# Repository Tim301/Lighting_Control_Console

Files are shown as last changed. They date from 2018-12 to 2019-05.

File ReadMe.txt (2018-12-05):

# Lighting_Control_Console
An open source lighting control console developed by MASTER's degree students of DREAM course at Valenciennes.
-> https://formations.uphf.fr/cdm/subProgram/FR_RNE_0593279U_PR_SOF-15676/FR_RNE_0593279U_PR_SOF-15679

DMX_Core.ino use Arduino Uno to create DMX512 signals for RS485 chip. // Actually in progress.
  Equipements:
   - Arduino Uno
   - Grove Dmx512 or similar
   - Cables
  How to use:
  Connect DMX chip input pin to Arduino's TX pin.
  
Attiny_Fader.ino use a Attiny85 to send and receive fader position by way of I2C.
  Equipements:
   - Attiny 85
   - L9110H H Bridge (DIP)
   - Motorized fader like SL9/01V96     // We use a PRO-Fader MF-914PFL-B10K-10V
 See Pinout:    // Not available yet

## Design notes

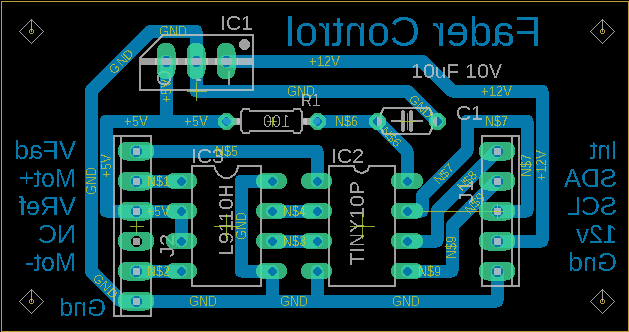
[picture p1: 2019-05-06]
PCB_Fader/PCB.png

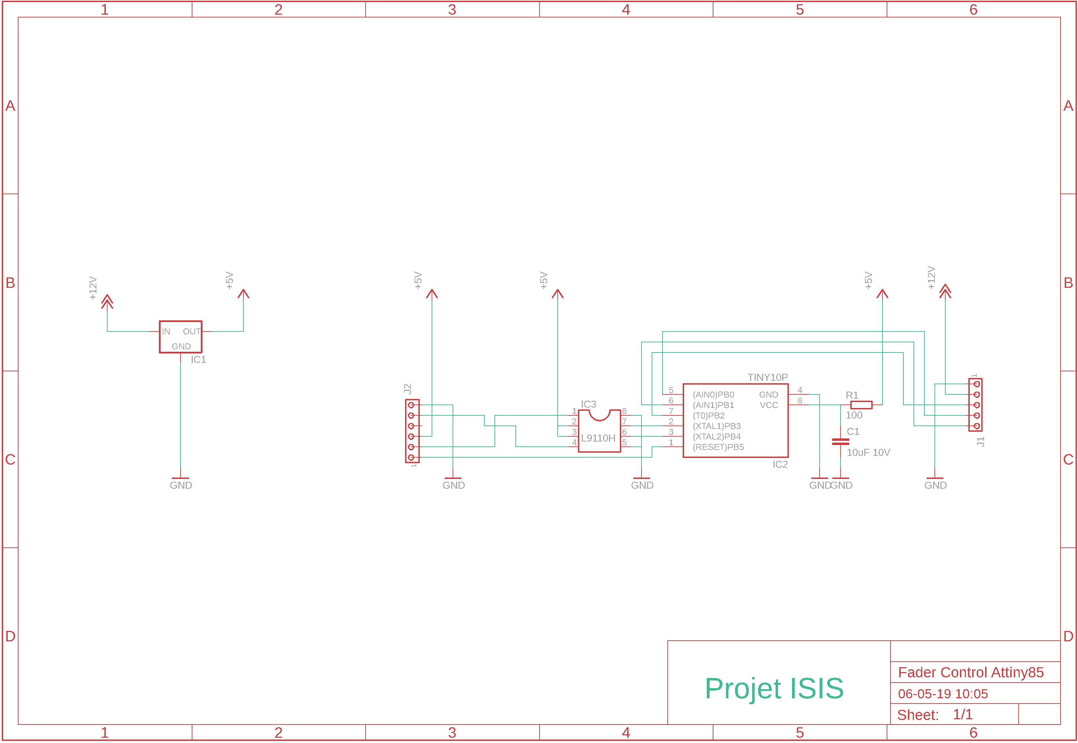
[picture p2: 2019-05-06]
PCB_Fader/Schema.png

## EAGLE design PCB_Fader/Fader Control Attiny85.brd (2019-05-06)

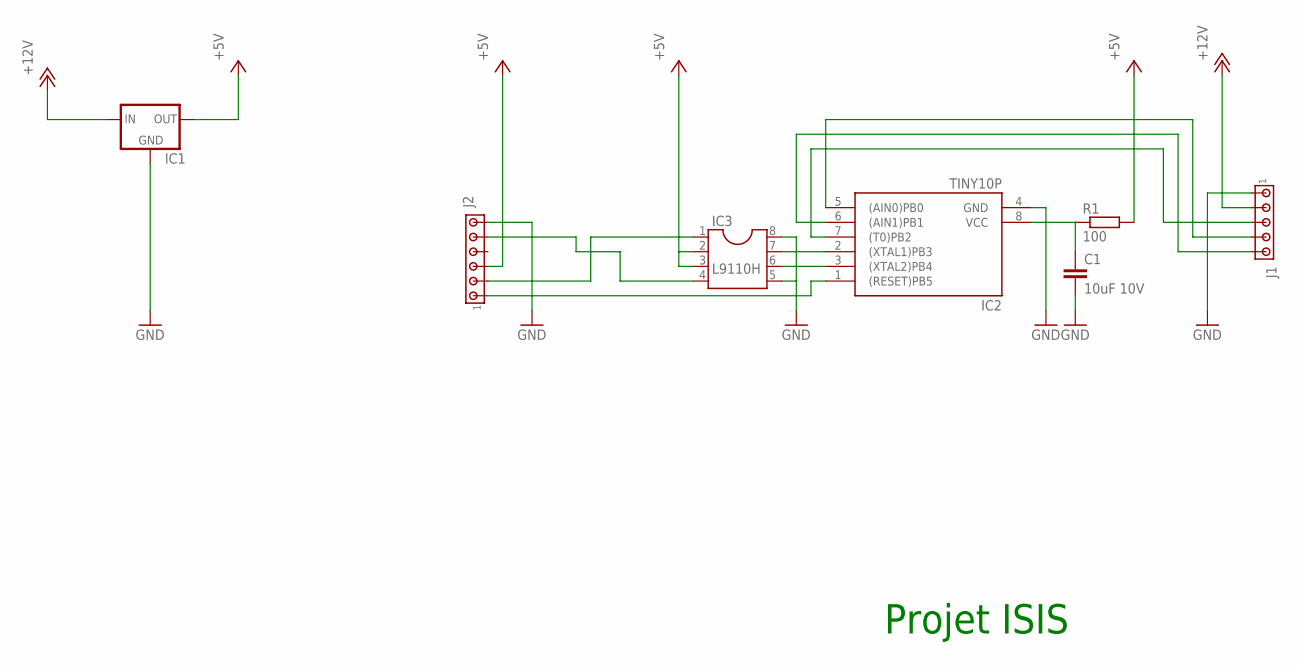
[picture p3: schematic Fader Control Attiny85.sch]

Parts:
C1: 10uF 10V; C050-024X044
IC1: 78MXXS
IC2: TINY10P; DIL08
IC3: L9110H; DIL08
J1: MTA05-100; 10X05MTA
J2: MTA06-100; 10X06MTA
R1: 100; 0204/7

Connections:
+5V: IC1.OUT, IC3.2, IC3.3, J2.3, R1.2
+12V: IC1.IN, J1.2
GND: C1.2, IC1.GND, IC2.4 (GND), IC3.5, IC3.8, J1.1, J2.6
unnamed: IC3.1, J2.2
unnamed: IC3.4, J2.5
unnamed: IC2.3 ((XTAL2)PB4), IC3.6
unnamed: IC2.2 ((XTAL1)PB3), IC3.7
unnamed: IC2.1 ((RESET)PB5), J2.1
unnamed: C1.1, IC2.8 (VCC), R1.1
unnamed: IC2.7 ((T0)PB2), J1.3
unnamed: IC2.6 ((AIN1)PB1), J1.5
unnamed: IC2.5 ((AIN0)PB0), J1.4

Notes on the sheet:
Projet ISIS

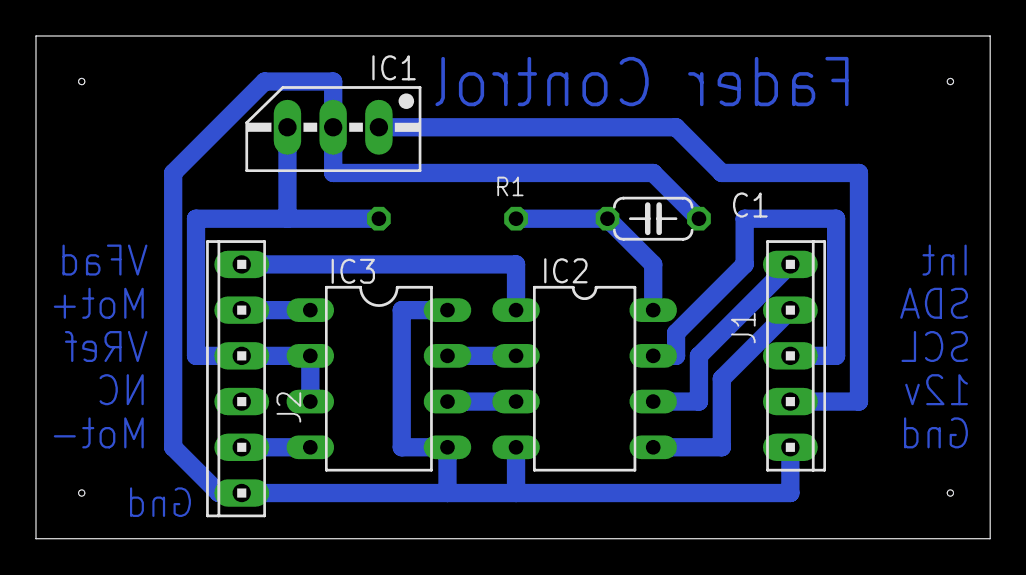
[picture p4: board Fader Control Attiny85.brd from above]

Board: 2 copper layers, 53.0 x 27.9 mm, 7 parts (1 on the bottom side), 12 nets.

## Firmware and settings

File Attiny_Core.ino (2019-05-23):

/**************************************************************************/
/*!
    @file     Attiny_Core.ino
    @author   Tim301 & AlexandreBouton
    TinyWire:
      See TinyWire LICENSE, copyright 2017 by Rambo
      https://github.com/rambo/TinyWire/tree/rollback/TinyWireS
    EVERYTHING LEFT:
      License MIT,
    Software for Attiny85 to position motorized fader through i2c.
    @section  Audiovisual
    v1.0
    @comment  Workfull version but can be optimize.
*/
/**************************************************************************/

#include "TinyWireS.h"

#define I2C_SLAVE_ADDR  0x28        // i2c slave address
#define INT 1                       // Pin 1 wired to Raspberry pi to enable ATtiny
#define HBA 3                       // Pin 2 wired to Logical Input B of the H Bridge
#define HBB 4                       // Pin 3 wired to Logical Input A of the H Bridge
/* If the fader go to the wrong way, switch pin number of HBA & HBB.*/

#define ADC 0                       // Pin 1 used as ADC
/* Pin 1 is used by default as Reset. Attiny85's fuses must be set as following in AVRDUDE 
 * to disable it: -U lfuse:w:0x62:m -U hfuse:w:0x5f:m -U efuse:w:0xff:m 
 * Links: http://www.engbedded.com/fusecalc/ & https://github.com/zkemble/AVRDUDESS */
 
#define wait 1

uint16_t val = 0;                   // Fader value from the ADC 10bit
uint16_t target = 0;                // Target position  8bit send from i2c
const uint8_t delta = 2;            // Hysteresis
float start = 0;                    // Initialize counter


void setup() {
  pinMode(HBA, OUTPUT);             // Set pin 2 as output
  pinMode(HBB, OUTPUT);             // Set pin 3 as output
  pinMode(INT, INPUT);              // Set pin 6 as input
  go_to_zero();                     // Position fader to 0
  TinyWireS.begin(I2C_SLAVE_ADDR);  // Start ATtiny as i2c slave at defined adress
}

/**************************************************************************/

void position()
{ // Move the fader to the target position.

  val = analogRead(ADC);

  if (val > (target + delta)) {
    digitalWrite(HBA, LOW);           // Make the fader moving down
    digitalWrite(HBB, HIGH);
    delay(wait);                      // Do oscillations if we don't put outputs at low state.
    digitalWrite(HBA, LOW);           // Make the fader stop
    digitalWrite(HBB, LOW);
  }

  else if (val < (target - delta)) {
    digitalWrite(HBA, HIGH);          // Make the fader moving up
    digitalWrite(HBB, LOW);
    delay(wait);
    digitalWrite(HBA, LOW);           // Make the fader stop
    digitalWrite(HBB, LOW);
  }
}

/**************************************************************************/

void send_value()
{
  uint16_t read_val = analogRead(ADC);
  uint8_t tmp = read_val >>= 2;
  TinyWireS.send(tmp);
}

/**************************************************************************/

//Enable the motor for 200ms
void go_to_zero()
{
  digitalWrite(HBA, LOW);           // Make the fader moving down
  digitalWrite(HBB, HIGH);
  //Wait the fader is down
  delay(200);
  digitalWrite(HBA, LOW);           // Make the fader stop
  digitalWrite(HBB, LOW);
}

/**************************************************************************/

//Enable the motor for 200ms
void go_to_top()
{
  digitalWrite(HBA, HIGH);          // Make the fader moving up
  digitalWrite(HBB, LOW);
  delay(200);
  digitalWrite(HBA, LOW);           // Make the fader stop
  digitalWrite(HBB, LOW);
}

/**************************************************************************/

void loop() {
  if (digitalRead(1) == 0)
  {
    //The master (raspberry) send a value
    target = TinyWireS.receive();
    target <<= 2;
    //Take the current fader's position
    val = analogRead(ADC);
    if (target == 132) {                    // Send postion if get 33 from i2c
      send_value();
    }
    else {
      //If target and val are not equals
      //(i.e : if fader's position is not the wanted's position)
      if (target != 0 && target != 1020 && target != val) {
        start = millis();                                               // Start counter
        while ((val > (target + delta)) || (val < (target - delta)))    // While fader is not inside the hysteresis range
        {
          //For more precision the fader is mooved 50 time
          for (int i = 0; i < 50; i++)
          {
            val = analogRead(ADC);
            position();
          }
          if (millis() - start > 500) {                                // If time spended to positionning > 500 ms, quit the while
            break;
          }
        }
      }

      //else if the fader has to go down and is not down
      else if (target == 0 && val != 0)
      {
        go_to_zero();
      }

      //else if the fader has to go up and is not up
      //be careful to the value ! It's not 255 but 255>>=2
      else if (target == 1020 && val != 1020)
      {
        go_to_top();
      }
      send_value();
    }
  }
}

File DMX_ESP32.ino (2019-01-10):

/**************************************************************************/
/*!
    @file     DMX_ESP32.ino
    @author   Tim301
    LXESP32DMX:
      License BSD, see LXESP32DMX LICENSE, copyright 2017 by Claude Heintz
    EVERYTHING LEFT:
      License MIT,
    Simple Lighting Console with 12 channels using ESP32 DMX Driver
    @section  HISTORY
    v1.01
*/
/**************************************************************************/

#include <LXESP32DMX.h>
#include "esp_task_wdt.h"

#define DMX_SERIAL_OUTPUT_PIN 17            //Define TX pin

#define CH1 36                              //Define Channel_1 pin
#define CH2 39
#define CH3 34
#define CH4 35
#define CH5 32
#define CH6 33
#define CH7 25
#define CH8 26
#define CH9 27
#define CH10 14
#define CH11 12
#define CH12 13
#define MASTER 15

uint8_t dmxbuffer[DMX_MAX_FRAME];           //Array to store DMX values

/************************************************************************/

void setup() {
  
  Serial.begin(115200);
  Serial.println("setup");
   
  pinMode(DMX_SERIAL_OUTPUT_PIN, OUTPUT);
  ESP32DMX.startOutput(DMX_SERIAL_OUTPUT_PIN);
  setupADC();                               //Lunch ADC setup
  
  Serial.println("setup complete");
}

/************************************************************************/

  /*  ADC Config parameters  */
void setupADC() {
  analogSetWidth(12);                       //Sets the sample bits and read resolution.
  analogSetCycles(8);                       //Set number of cycles per sample.
  analogSetSamples(1);                      //Set number of samples in the range.
  analogSetClockDiv(1);                     //Set the divider for the ADC clock.
  analogSetAttenuation(ADC_11db);           //Set the attenuation for all channels.
  analogSetPinAttenuation(CH1, ADC_11db);   //Set the attenuation for particular pin.
  adcAttachPin(CH1);                        //Attach pin to ADC.
  adcStart(CH1);                            //Start ADC conversion on attached pin's bus.
  analogSetPinAttenuation(CH2, ADC_11db);
  adcAttachPin(CH2);
  adcStart(CH2);
  analogSetPinAttenuation(CH3, ADC_11db);
  adcAttachPin(CH3);
  adcStart(CH3);
  analogSetPinAttenuation(CH4, ADC_11db);
  adcAttachPin(CH4);
  adcStart(CH4);
  analogSetPinAttenuation(CH5, ADC_11db);
  adcAttachPin(CH5);
  adcStart(CH5);
  analogSetPinAttenuation(CH6, ADC_11db);
  adcAttachPin(CH6);
  adcStart(CH6);
  analogSetPinAttenuation(CH7, ADC_11db);
  adcAttachPin(CH7);
  adcStart(CH7);
  analogSetPinAttenuation(CH8, ADC_11db);
  adcAttachPin(CH8);
  adcStart(CH8);
  analogSetPinAttenuation(CH9, ADC_11db);
  adcAttachPin(CH9);
  adcStart(CH9);
  analogSetPinAttenuation(CH10, ADC_11db);
  adcAttachPin(CH10);
  adcStart(CH10);
  analogSetPinAttenuation(CH11, ADC_11db);
  adcAttachPin(CH11);
  adcStart(CH11);
  analogSetPinAttenuation(CH12, ADC_11db);
  adcAttachPin(CH12);
  adcStart(CH12);
  analogSetPinAttenuation(MASTER, ADC_11db);
  adcAttachPin(MASTER);
  adcStart(MASTER);  
}

/*   ADC fonction  */
uint8_t ADC(uint8_t x){                     
    uint8_t preset = (analogRead(x)) >> 4;        //Get value from CHx
    uint8_t master = (analogRead(MASTER)) >> 4;   //Get value from MASTER
    uint8_t result = (unsigned int) (preset*master/255);  //Multiply Channel level by Master factor
  return result;
}

/*  DMX Generator fonction  */
void copyDMXToOutput(void) {
  xSemaphoreTake( ESP32DMX.lxDataLock, portMAX_DELAY );
  for (int i=1; i<DMX_MAX_FRAME; i++) {
      ESP32DMX.setSlot(i , dmxbuffer[i]);
   }
   xSemaphoreGive( ESP32DMX.lxDataLock );
}

/************************************************************************/

void loop() {
  
  /*  Save Channels State   */
  dmxbuffer[1] = ADC(CH1);
  dmxbuffer[2] = ADC(CH2);
  dmxbuffer[3] = ADC(CH3);
  dmxbuffer[4] = ADC(CH4);
  dmxbuffer[5] = ADC(CH5);
  dmxbuffer[6] = ADC(CH6);
  dmxbuffer[7] = ADC(CH7);
  dmxbuffer[8] = ADC(CH8);
  dmxbuffer[9] = ADC(CH9);
  dmxbuffer[10] = ADC(CH10);
  dmxbuffer[11] = ADC(CH11);
  dmxbuffer[12] = ADC(CH12);

  //Serial.println((analogRead(MASTER))/16);
  copyDMXToOutput();                            //Send channels values to DMX Generator Fonction
  esp_task_wdt_feed();
  
}

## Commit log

2019-02-12 I2C libraries and source code
    These I2C libraires allow the RPI to communicate with an LCD I2C screen
2019-02-16 Add files via upload
    Simple benchmark for ADC MCP3008
2019-02-26 Create dmx.py
    First test dmx generator for raspberry pi.
2019-02-26 Update and rename dmx.py to DMX.py
    Personal DMX library for Raspberry Pi using Python.
    v1.0 - Works
2019-03-04 Add files via upload
    This program display a fader's value converted with an ADC on a little OLED screen. There is a hudge latency problem. If someone fix this lattency, let me know.
    [Fader_value_display.py]
2019-04-14 ATtiny and rpi communication
    Sending ADC's ATtiny values to the Rpi with I2C protocol
2019-05-06 Add files via upload
    PCB files for fader control with attiny.
    [Fader Control Attiny85.brd, Fader Control Attiny85.sch]
2019-05-23 Add files via upload
    DMX+i2c fader
